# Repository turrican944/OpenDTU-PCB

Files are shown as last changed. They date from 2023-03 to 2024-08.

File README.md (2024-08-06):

# OpenDTU-PCB      
   
Eine Leiterplatte für OpenDTU oder Ahoy mit Oled Display.
Gehäuse Gainta G203CMF 115 x 65 x 40

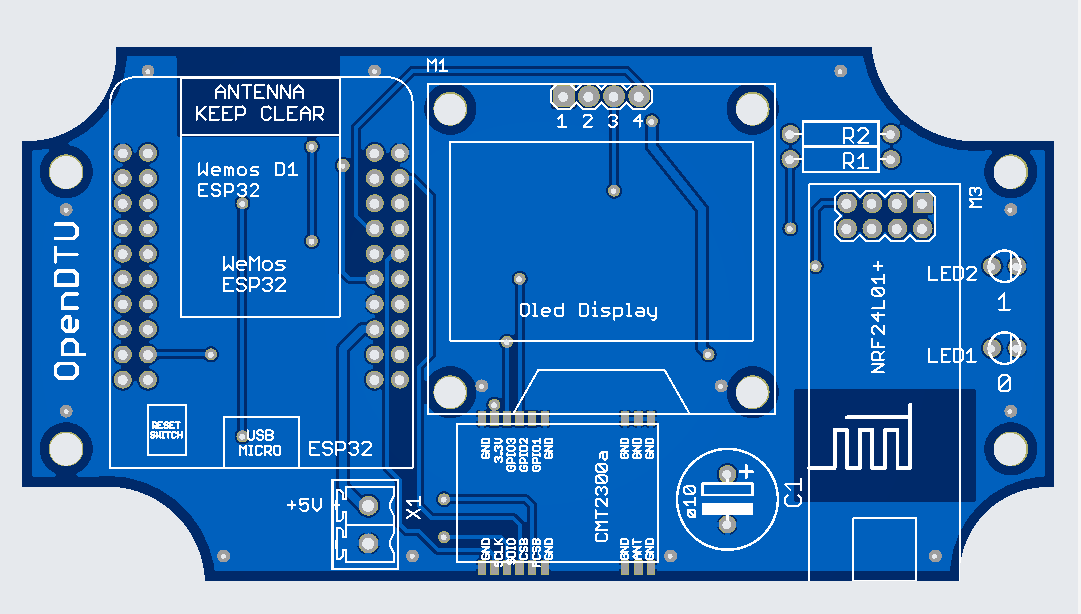
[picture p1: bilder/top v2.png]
Top

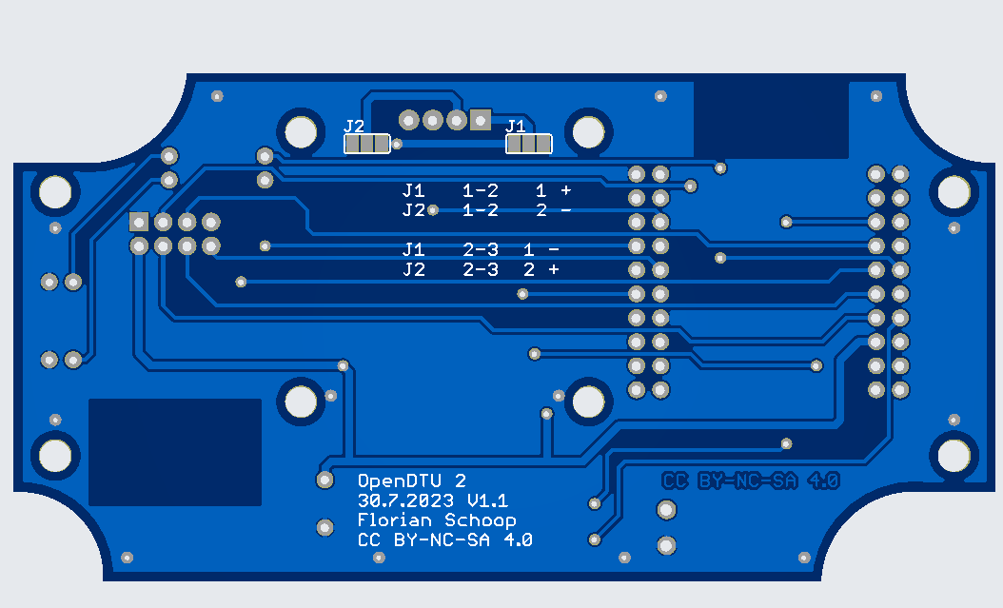
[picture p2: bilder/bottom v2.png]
Bottom

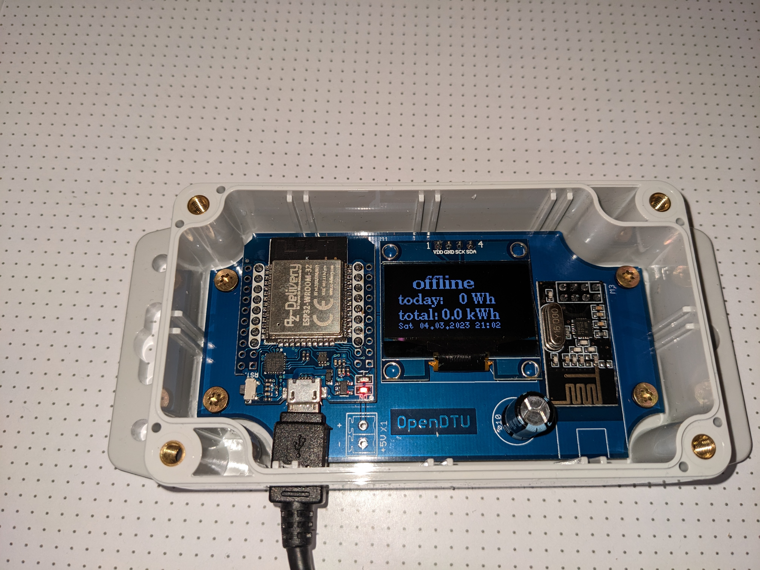
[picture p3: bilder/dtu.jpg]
dtu


Neue PCB Version jetzt mit CMT2300a und NRF24L01+
Es kann ein 1.3" Oled oder 0.9" I2C Oled verbaut werden. Die Polung der Spannungsversorgung ist über Jumper einstellbar. NRF24L01+ als Standart mit PCB Antenne oder auch als Version mit externer Antenne.
Es kann ein Wemos D1 mini oder ein Wemos D1 ESP32 verbaut werden. Für OpenDTU wird der Wemos D1 ESP32 benötigt.

Das GPIO Pinning ist das Standartpinning vom AhoyDTU. OpenDTU muss entsprechend auf angepasst werden (Deviceprofil.json für OpenDTU mit und ohne Display).
GPIO Pins OpenDTU: <br>
NRF: <br>
IO17 IRQ <br>
IO16 CE <br>
IO05 CS <br>
IO23 MOSI <br>
IO19 MISO <br>
IO18 SCK <br>
Display: <br>
IO22 SCL <br>
IO21 SDA <br>
CMT2300a: <br>
IO14 SDIO <br>
IO12 SCLK <br>
IO27 CSN <br>
IO26 FCSB <br>
IO04 GPIO2 <br>
IO13 GPIO3 <br>
LED: <br>
IO32 LED0 <br>
IO33 LED1 <br>

Die Pins legt man am besten schon in der Platformio.ini fest. Der ESP D1 Mini ist in der Platformio.ini schon enthalten allerdings sind dort IO16 und IO17 vertauscht. Flasht man nun den ESP32 wenn der schon auf de Platine ist, gibts beim Starten immer einen Interrupt vom Funkmodul (Pinning stimmt ja nicht) und ggf. kommt man dann nicht auf das WebIF. Also am besten die Pins des Funkmodul schon vorher ändern oder ESP32 erst flashen, devices config nachladen und ESP32 auf der Platine verbauen.

Bauteile: <br>
Wemos D1 ESP32 (für OpenDTU oder Ahoy) https://www.az-delivery.de/collections/esp32/products/esp32-d1-mini <br>
NRF24L01+ Funkmodul <br>
470uF Kondensator (es müssen wohl nicht umbedingt 470uF sein, weniger geht wohl auch ggf das nehmen was in der Bastelkiste grade ist)<br>
Minicombicon wenn die Stromversorgung nicht über den USB Port erfolgen soll. https://www.reichelt.de/stiftleiste-2-pol-rm-3-81-mm-0--ctb932ve-2-p292580.html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 <br>
Gainta G203CMF 115 x 65 x 40 Gehäuse https://www.conrad.de/de/p/gainta-g203cmf-universal-gehaeuse-115-x-65-x-40-polycarbonat-hellgrau-klar-1-st-2356897.html <br>
Ahoy mit einem ESP32 habe ich auf der aktuelle Platine nicht getestet.

Olimex ESP32 Poe
Adapterplatine CMT2300a auf Olimex poe Board
Olimex1
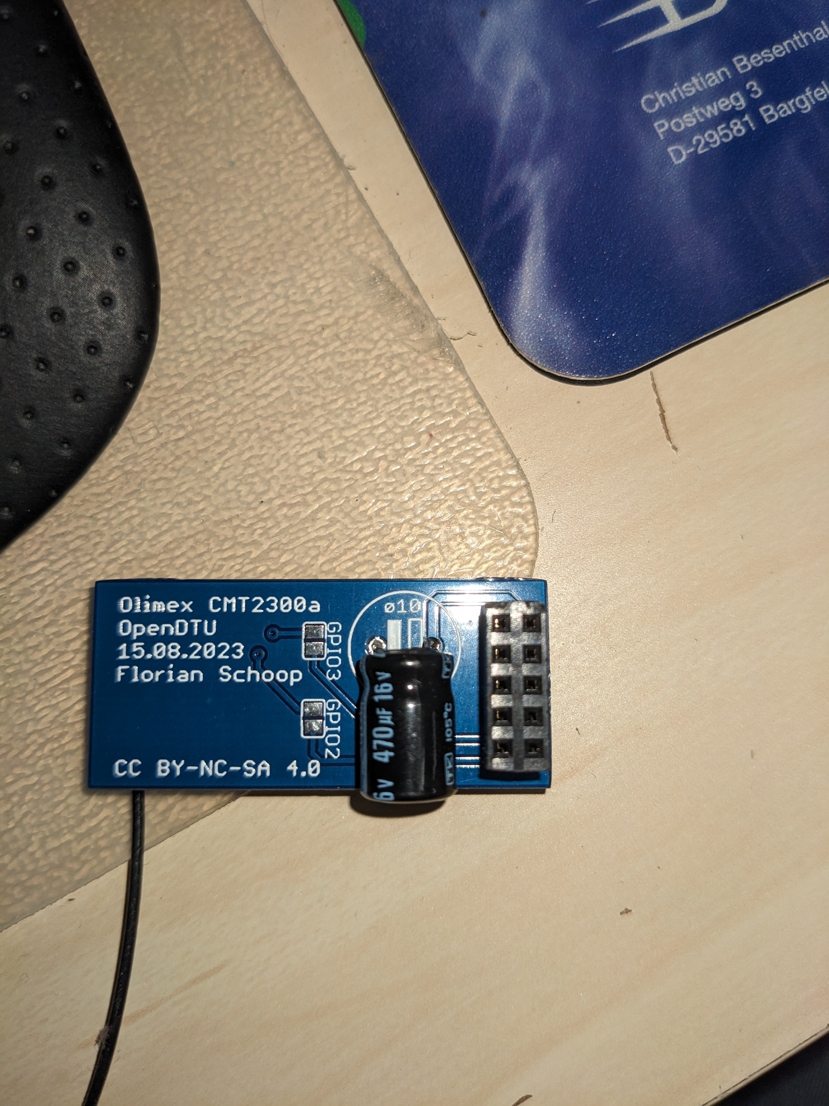
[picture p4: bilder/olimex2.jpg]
Olimex1

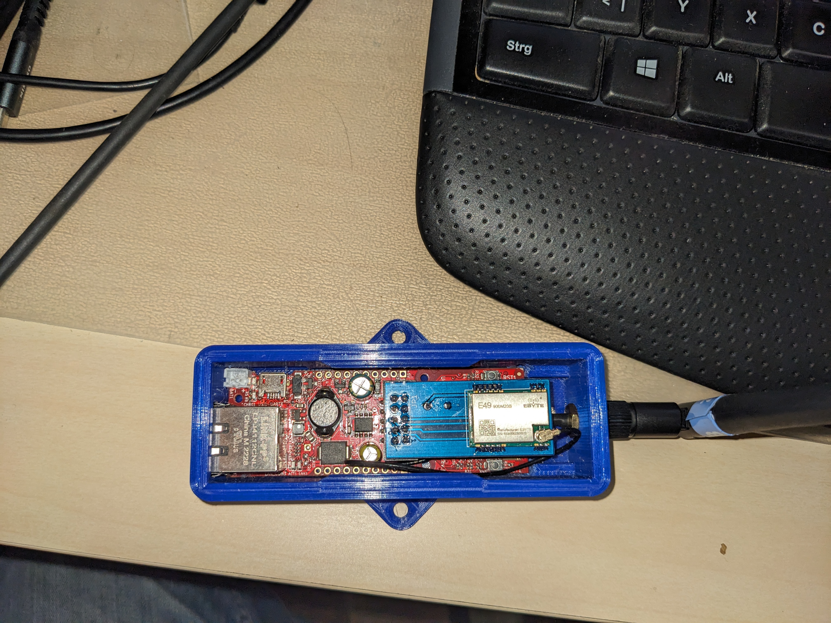
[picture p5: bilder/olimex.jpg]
Olimex1

Die Gerberdaten der Olimex Platine sind auch Panel 2x4 vorhanden.

Gehäuse für den Olimex ISO
https://www.thingiverse.com/thing:6489072 <br>
Gehäuse Olimex https://www.thingiverse.com/thing:4860626 (das ist das auf dem Bild)



Dieses Werk ist lizenziert unter einer [Creative Commons Namensnennung - Nicht-kommerziell - Weitergabe unter gleichen Bedingungen 4.0 International Lizenz](http://creativecommons.org/licenses/by-nc-sa/4.0/).

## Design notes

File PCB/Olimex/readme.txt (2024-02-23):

olimex_muster.zip enthält alle Gerber und Excellon Daten zum Fertigen z.b. bei JLCPCB 8 Muster sind auf einer Leiterplatte.
Wenn man die Standartmenge mit 5 Leiterplatten bestellt bekommt man also 40 Leiterplatten 

olimex.zip enthält die Gerber, Excellon und Eagle Daten für eine Leiterplatte.

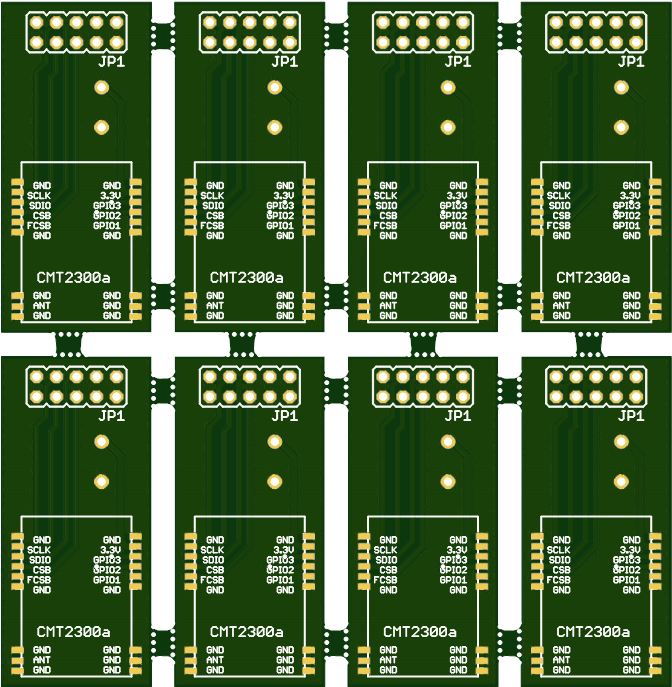
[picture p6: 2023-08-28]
PCB/Olimex/Untitled_Combined_Top.png

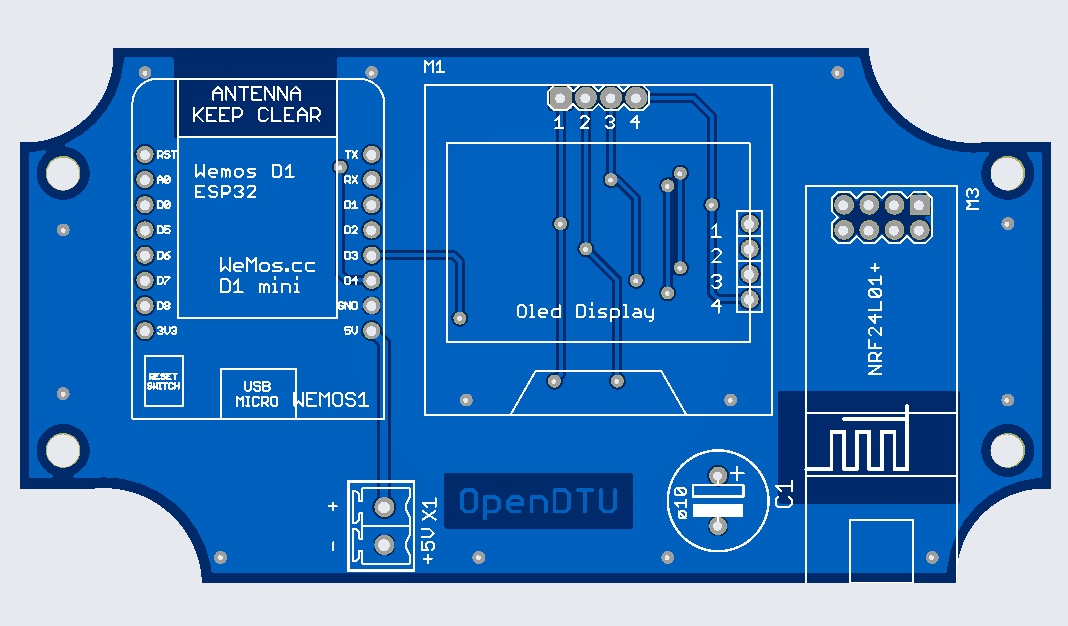
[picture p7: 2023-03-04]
bilder/Top.png

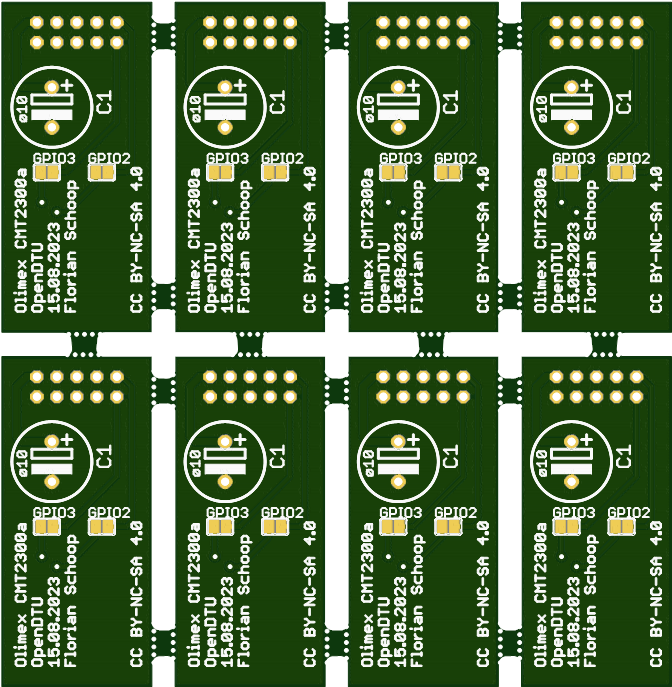
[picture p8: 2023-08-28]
PCB/Olimex/Untitled_Combined_Bottom.png

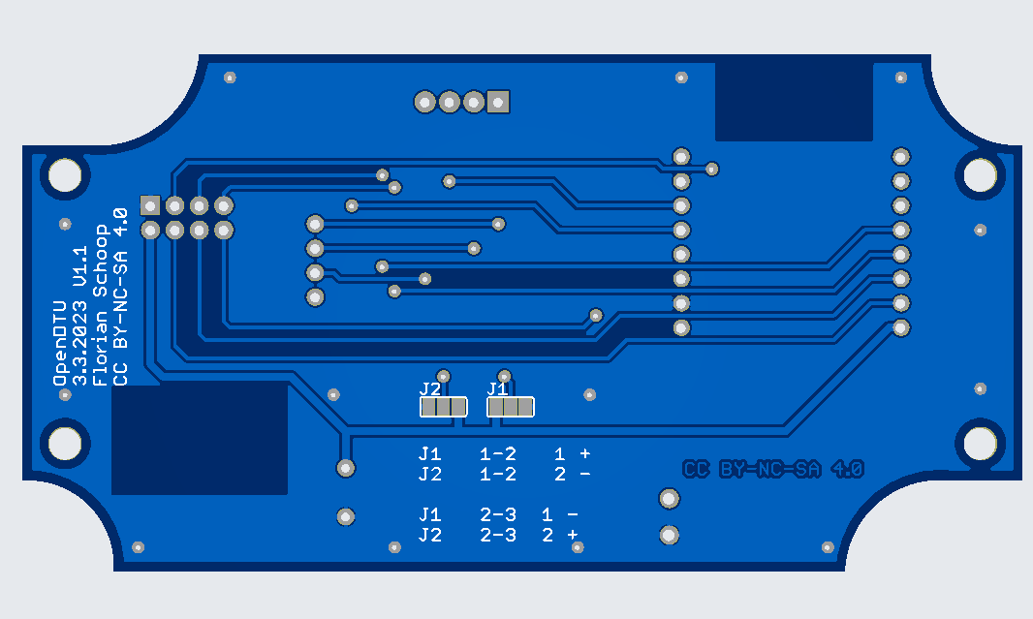
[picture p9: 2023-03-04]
bilder/bottom.png

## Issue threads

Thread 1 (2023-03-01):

Test PCBs // Add Contact Data

basst22778, 2023-03-01:
Hi,
Ich hätte Interesse an PCBs aus Deiner Testbestellung. Wenn du noch welche übrig hasts…

Es gibt aber keine Kontaktdaten in deinem Repo.

—
BassT

turrican944, 2023-03-01:
Moin
Ne sind noch keine Kontaktdaten drin, ich habe es auch noch nicht fertig.
Leiterplatten sind noch nicht da, aber ich habe davon dann auch leider
keine mehr über.

Gruß Florian

basst22778 ***@***.***> schrieb am Mi., 1. März 2023, 21:12:

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

basst22778, 2023-03-01:
Alles klar! dann warte ich mal ab ob das Layout bei Dir funktioniert und geb dann selbst ne Bestellung auf.

turrican944, 2023-03-02:
Moin
Ich gehe schon davon aus daß es funktioniert. Ich habe noch bischen was
geändert. Ein Text war noch versetzt und noch ein paar Masse
Durchkontaktierungen mehr rein, ich warte aber immer noch auf die erste
Charge. Die Änderungen sollte aber wenn die erste funktioniert auch passen.
Aber evtl Order ich nochmal nach weil natürlich alle Kumpels sowas wollen.
Aber es ist ja immer so Zeit ist knapp.

Gruß Florian

basst22778 ***@***.***> schrieb am Mi., 1. März 2023, 23:34:

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

Closed 2023-03-01.

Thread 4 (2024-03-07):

Kleiner Fehler im opendtu V2.pdf

swan99de, 2024-03-07:
In die Beschriftung für die Polung der Jumper hat sich im opendtu V2.pdf ein kleiner Fehler eingeschlichen.
J1 1-2 1+   J2 2-3 1-
J2 1-2 2-   J2 2-3 2+
Jumper2 ist 3x und Jumper1 nur 1x aufgeführt

Der Aufdruck auf der Platine ist korrekt
J1 1-2 1+
J2 1-2 2-

J1 2-3 1-
J2 2-3 2+

turrican944, 2024-03-08:
Moin
Guck an ist mir noch garnicht aufgefallen ;-) , ich habe es mal korrigiert, tippfehler kommen halt mal vor.

Closed 2024-03-08.

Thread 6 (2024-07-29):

WT32-ETH01 Variante?

KlausHans, 2024-07-29:
Hallo, coole Platine, die meiner all-in-one-Vorstellung sehr nahe kommt. Ich bin aber kein Fan von Wlan. Wäre es möglich, dass du eine Variante für das wt32-eth01-Board machst?
Ich bin leider mit PCB-Design komplett unbewandert und evtl ist es für dich ein Klacks.
Folgende Dinge schweben mir vor:
- Größe und Außenkontur ist egal, ich würde eh ein Gehäuse designen und 3D-drucken
- der Ethernetconnector würde wohl eine Art cutout benötigen, da er höher als die Pinsockel ist
- das WT32-ETH01 sollte so positioniert sein, dass der Ethernetconnector über den Rand hinaus ragt, damit er in einer Gehäusewand übergehen kann
- Display muss nicht direkt auf der Platine Platz finden, die Anschlüsse reichen

Vielleicht hast du eh schon mal drüber nachgedacht. Das Olimex-Board ist mMn unnötig teuer und Poe hat kaum jemand (ich persönlich kenne niemanden in meinem Bekanntenkreis).

turrican944, 2024-08-06:
Moin
Den kenn ich gar nicht.
Ich bin auch keine wirklicher Fan von WLAN , aber ich habe Power over Ethernet und deshalb mal den Adapter zum aufstecken auf den Olimex gemacht. Der kann aber nur HMS WR (ich habe zurzeit auch keine anderen). Ich wollte für den Olimex mal eine Platine machen wo Display und das NRF mit drauf ist (CMT kann ja weiter huckepack bleiben oder auch mit drauf) aber da ich weder das Display wirklich brauche noch die 2,4Ghz habe ich da bislang nix gemacht.
Ist ja nun nicht so dass es mal ebend schnell geht. Leiterplatten erstellen , dann muss ich das aufbauen und testen ob das alles geht. Momentan habe ich da wenig Zeit zu und die Geschichte Ethernet aber mit Netzteil ist irgendwie nix was ich brauchen könnte.
Wenn ich im Herbst/Winter vielleicht mal etwas Zeit finde und eine Platine mit Display usw für den Olimex machen sollte kann ich ja Mal schauen ob der andere mit Ethernet da auch rauf passt.

KlausHans, 2024-08-06:
Alles klar, vielen Dank für die Antwort. Verständlich.
Einer All-in-one-Platine für das Olimexboard wäre ich auch nicht abgeneigt. So viele Dtus braucht man ja nicht, da wären die Mehrkosten dafür auch ok.

turrican944, 2024-08-06:
Moin
für den Olimex habe ich das mal vor zu machen, weis aber noch nicht wann
ich dazu komme.  Denke das wird irgendwie herbst/winter werden.
Im Bild mal der Testaufbau Olimex mit NRF, CMT und Display.
Gruß Flo

Am Di., 6. Aug. 2024 um 14:05 Uhr schrieb KlausHans <
***@***.***>:

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

KlausHans, 2024-09-23:
Ich freue mich auf die Variante und bin gespannt.

Ich sehe kein Bild. 🤔

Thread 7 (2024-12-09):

Gehäuse aus dem 3d-Drucker

KlausHans, 2024-12-09:
Moin, ich wollte nur kurz mein Gehäuse zeigen, vllt ist es für den einen oder anderen interessant und evtl sogar eine Erwähnung in der Readme wert: https://www.printables.com/model/1102696-case-for-opendtu-pcb-by-turrican944

Ansonsten kann das issue direkt geschlossen werden. :)

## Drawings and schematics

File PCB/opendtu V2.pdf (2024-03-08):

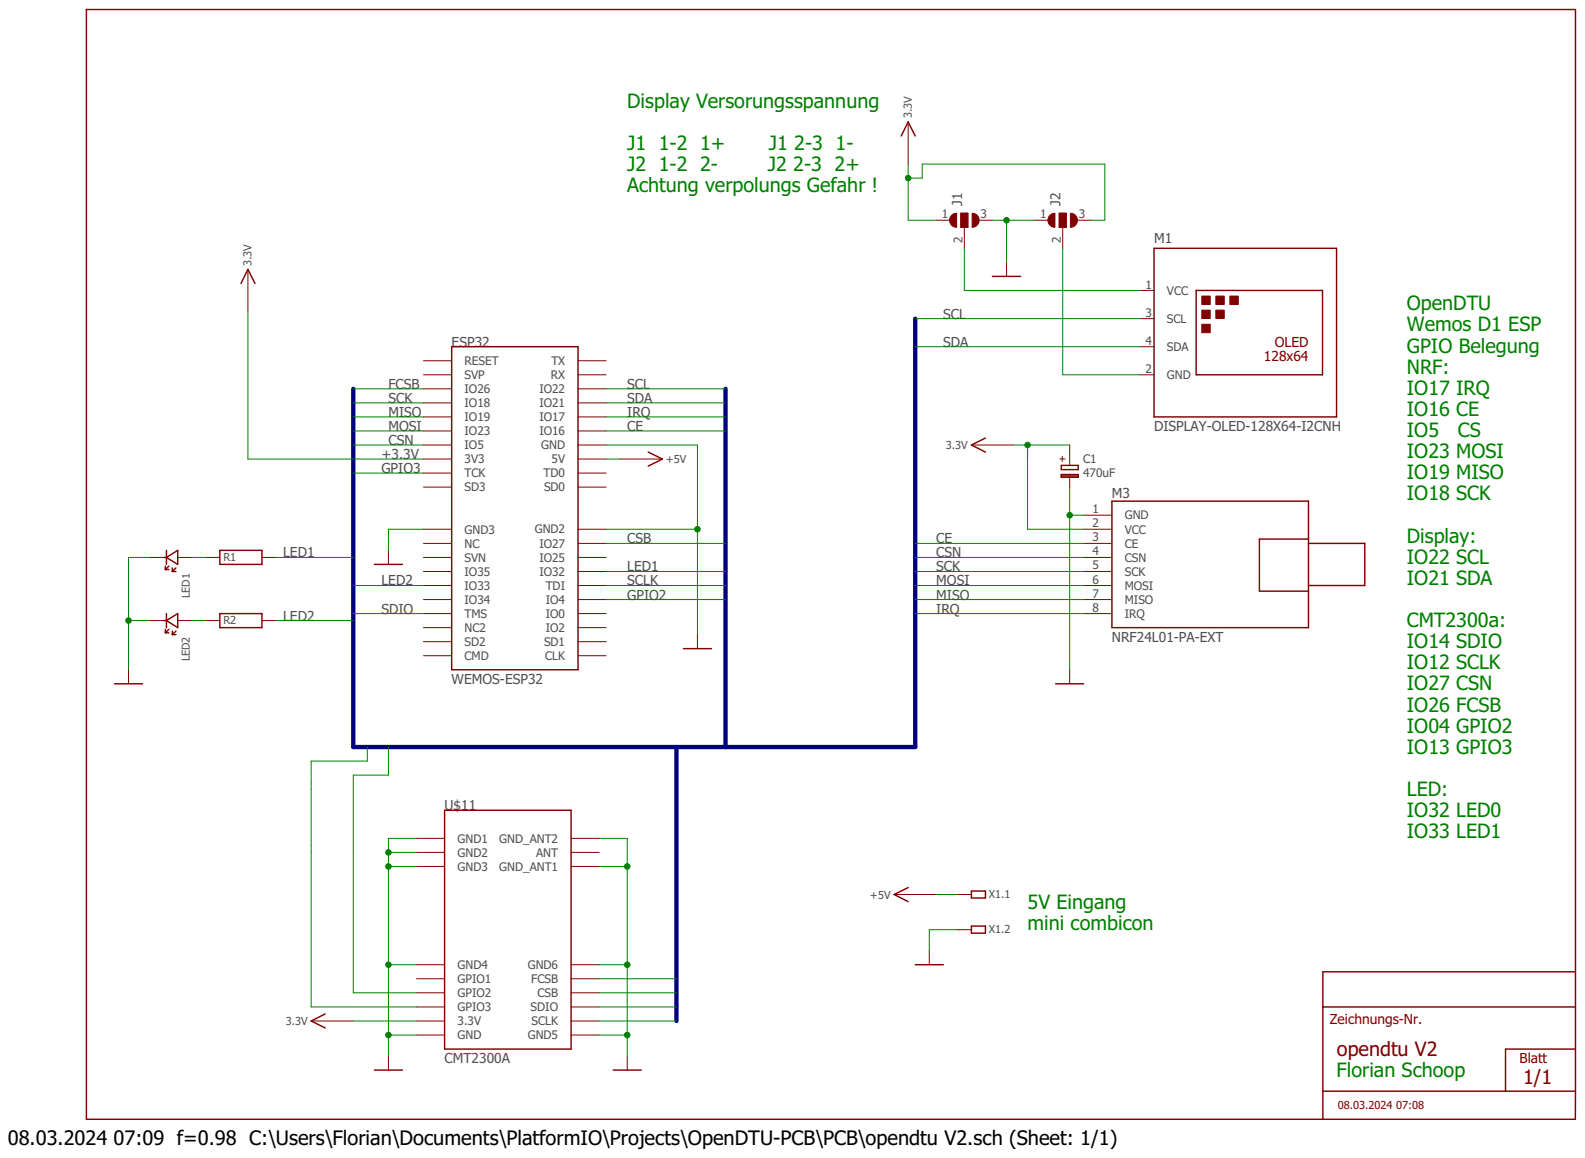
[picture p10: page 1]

SCK | SDA
MISO | IRQ

08.03.2024 07:09 f=0.98 C:\Users\Florian\Documents\PlatformIO\Projects\OpenDTU-PCB\PCB\opendtu V2.sch (Sheet: 1/1)

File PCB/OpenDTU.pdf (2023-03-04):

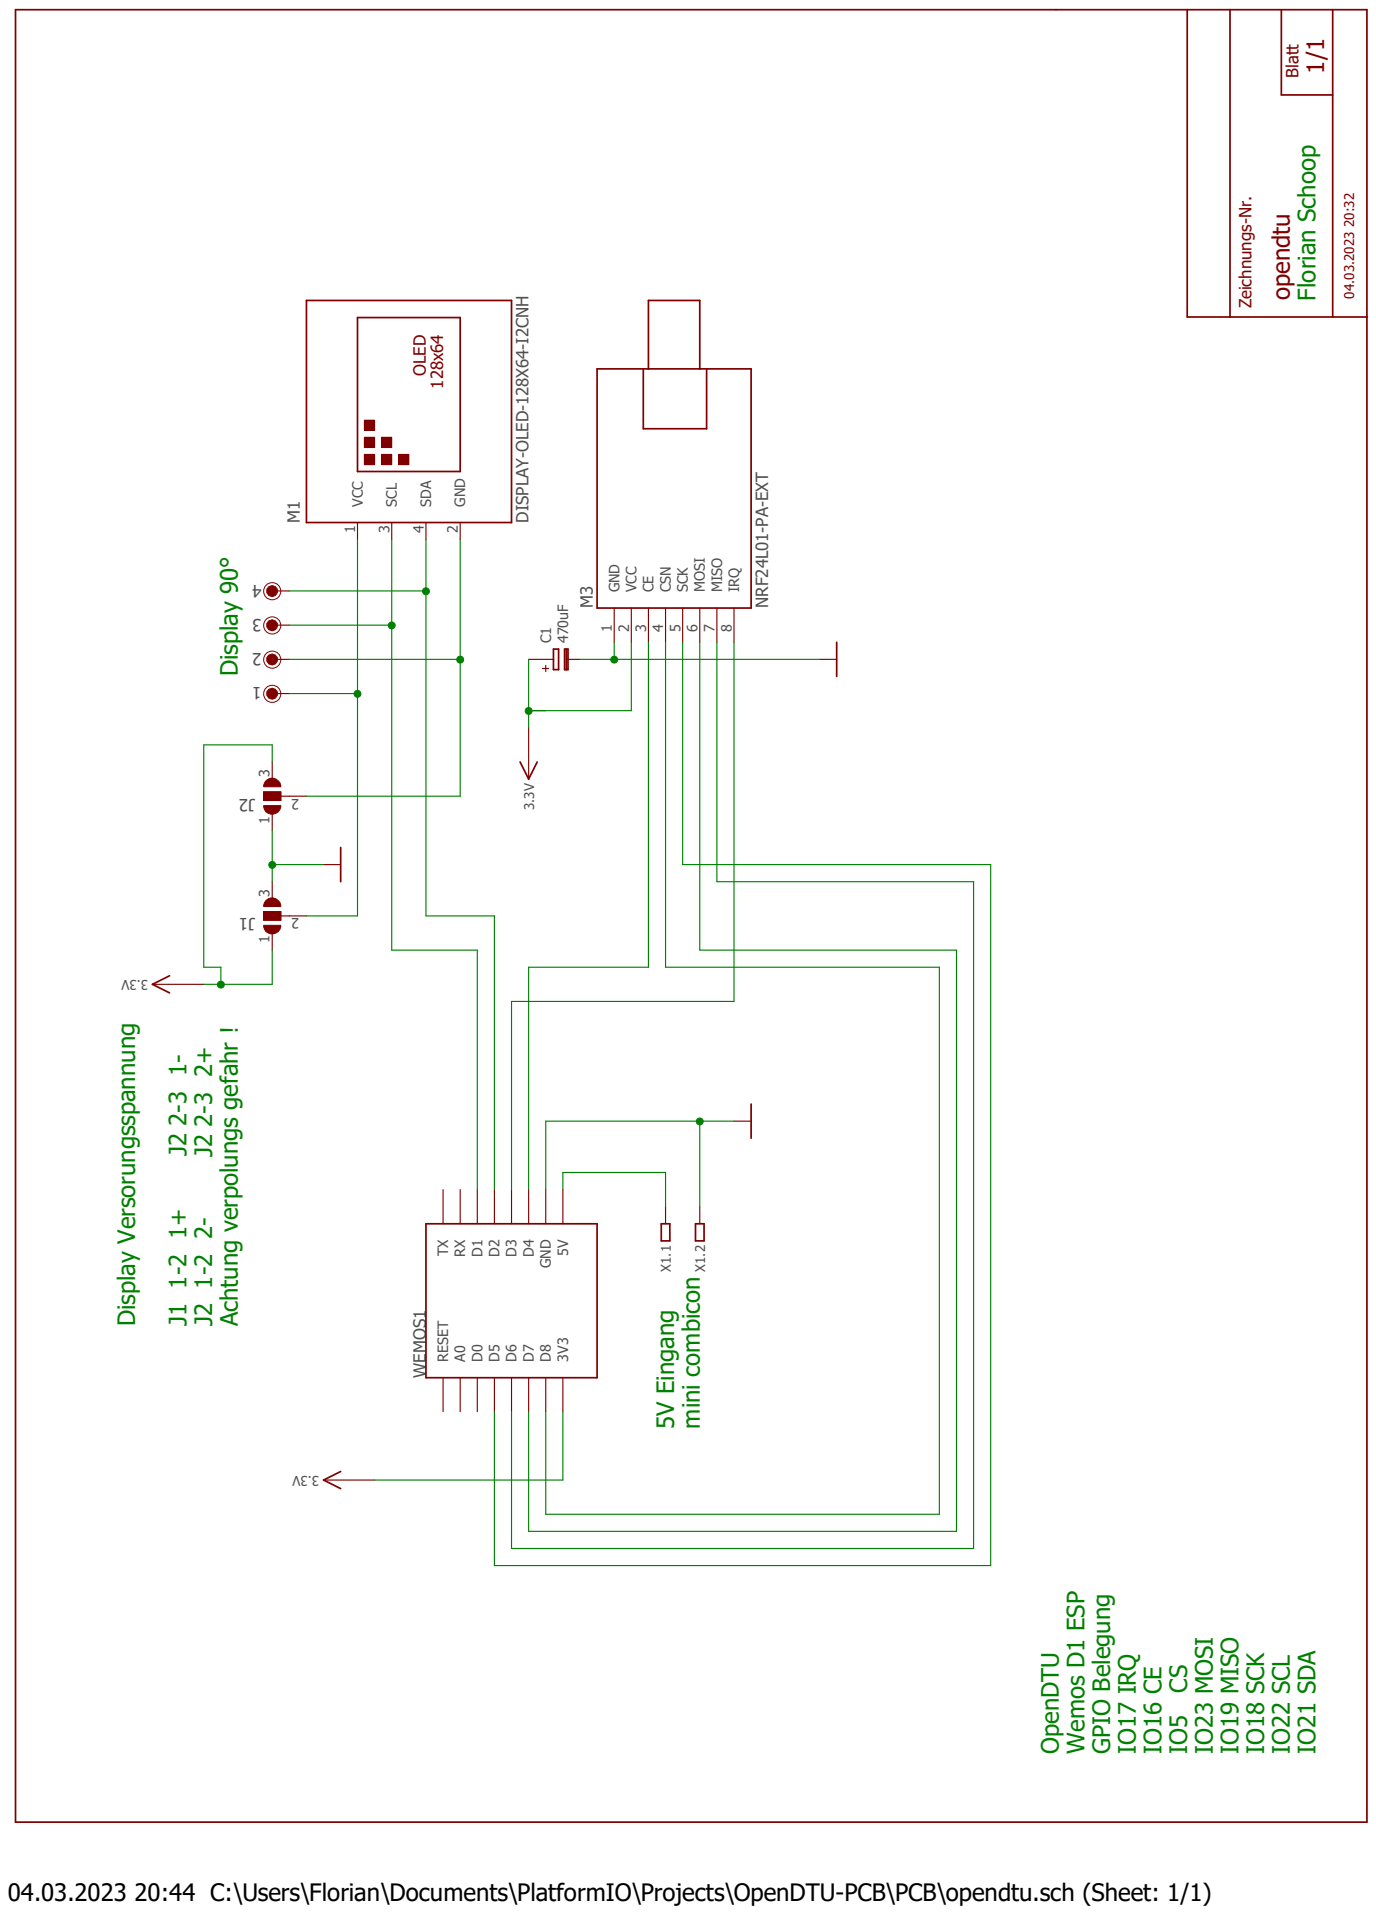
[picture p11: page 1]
1 VCC 2 CE; 3 CSN 4 SCK; 5 MOSI 6 MISO 7 IRQ; 8 M3 GND 2 VCC; 1 SCL 3 SDA

04.03.2023 20:44 C:\Users\Florian\Documents\PlatformIO\Projects\OpenDTU-PCB\PCB\opendtu.sch (Sheet: 1/1) NRF24L01⁻PA⁻EXT DISPLAY⁻OLED⁻¹²⁸X64⁻I2CNH

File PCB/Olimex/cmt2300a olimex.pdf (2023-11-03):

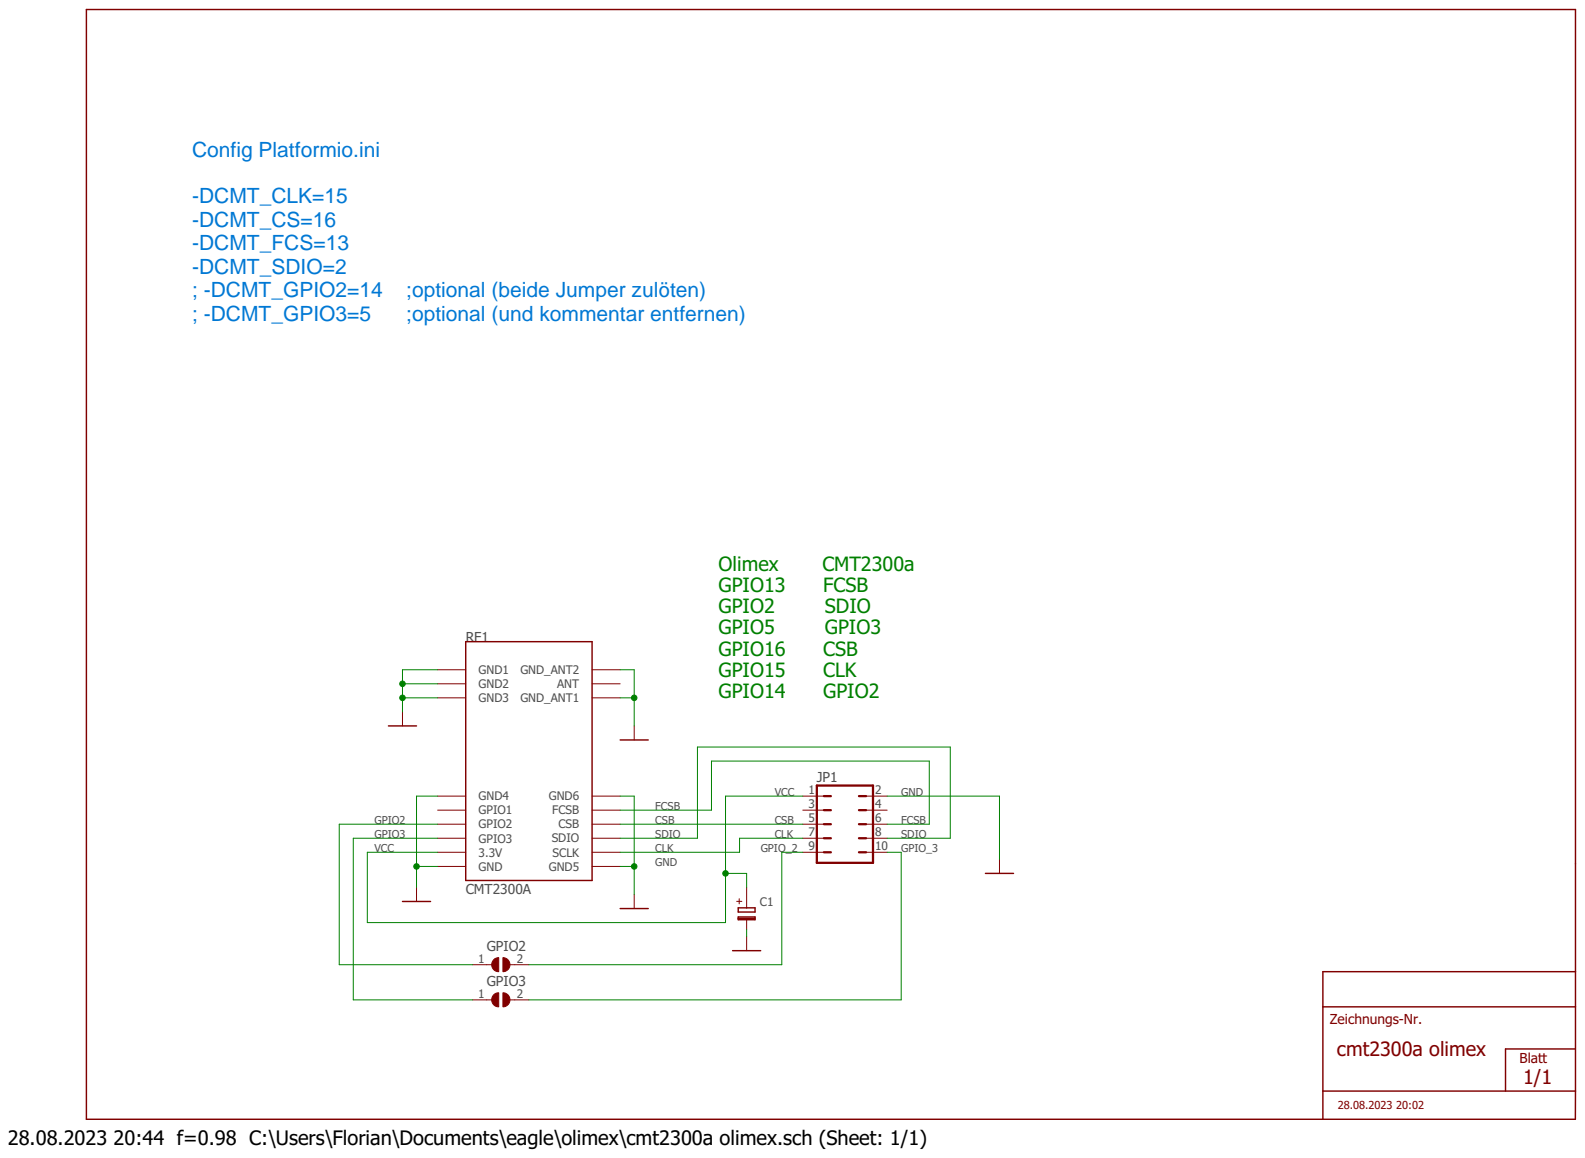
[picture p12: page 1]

3 5 | 4 6 SDIO
SDIO | FCSB GPIO3

28.08.2023 20:44 f=0.98 C:\Users\Florian\Documents\eagle\olimex\cmt2300a olimex.sch (Sheet: 1/1)

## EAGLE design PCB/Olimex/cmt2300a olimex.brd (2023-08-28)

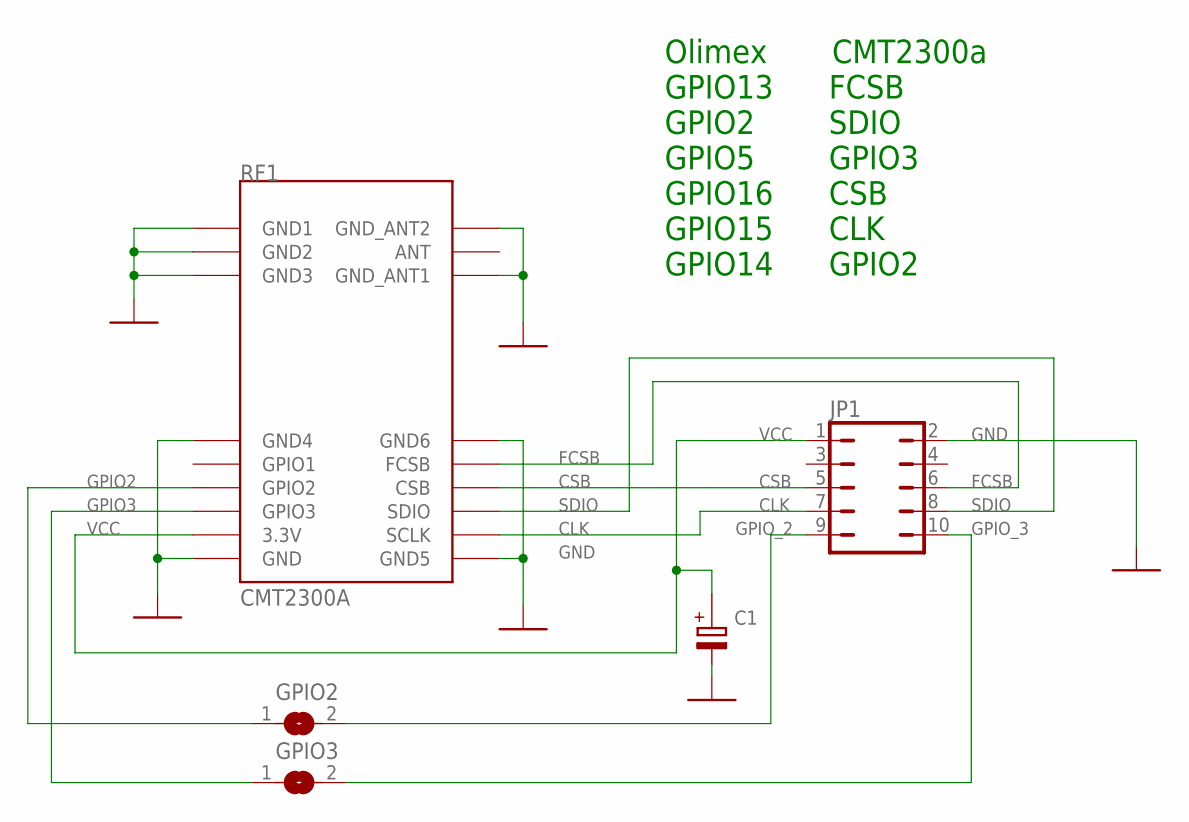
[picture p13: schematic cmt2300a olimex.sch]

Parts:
C1: S470µ/16; EB10D
GPIO2, GPIO3: SJ
JP1: JP5Q_OT
RF1: CMT2300A

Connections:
CLK: JP1.7, RF1.SCLK
CSB: JP1.5, RF1.CSB
FCSB: JP1.6, RF1.FCSB
GND: C1.-, JP1.2, RF1.GND, RF1.GND1, RF1.GND2, RF1.GND3, RF1.GND4, RF1.GND5, RF1.GND6, RF1.GND_ANT1, RF1.GND_ANT2
GPIO2: GPIO2.1, RF1.GPIO2
GPIO3: GPIO3.1, RF1.GPIO3
GPIO_2: GPIO2.2, JP1.9
GPIO_3: GPIO3.2, JP1.10
SDIO: JP1.8, RF1.SDIO
VCC: C1.+, JP1.1, RF1.3.3V

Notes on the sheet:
Olimex CMT2300a GPIO13 FCSB GPIO2 SDIO GPIO5 GPIO3 GPIO16 CSB GPIO15 CLK GPIO14 GPIO2

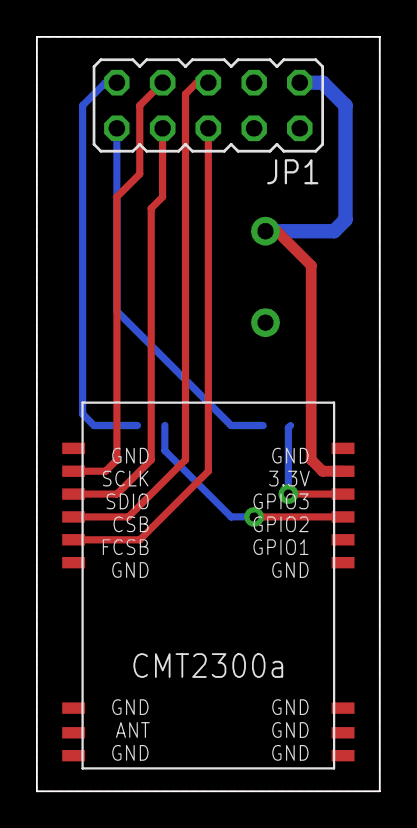
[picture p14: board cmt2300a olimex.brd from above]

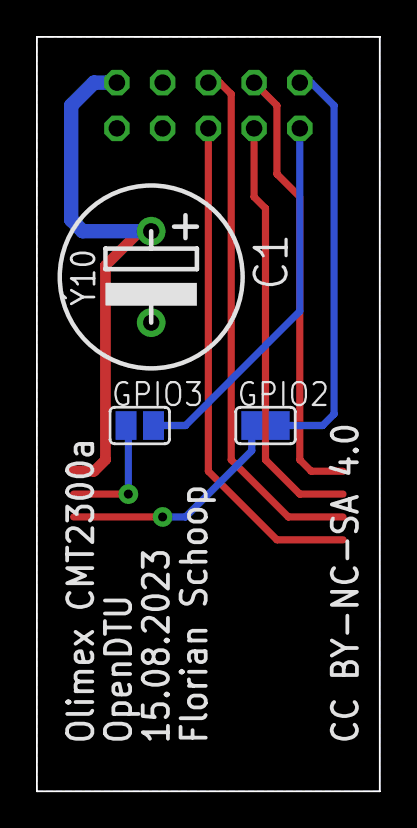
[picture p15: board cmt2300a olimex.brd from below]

Board: 2 copper layers, 19.1 x 41.9 mm, 5 parts (3 on the bottom side), 10 nets.

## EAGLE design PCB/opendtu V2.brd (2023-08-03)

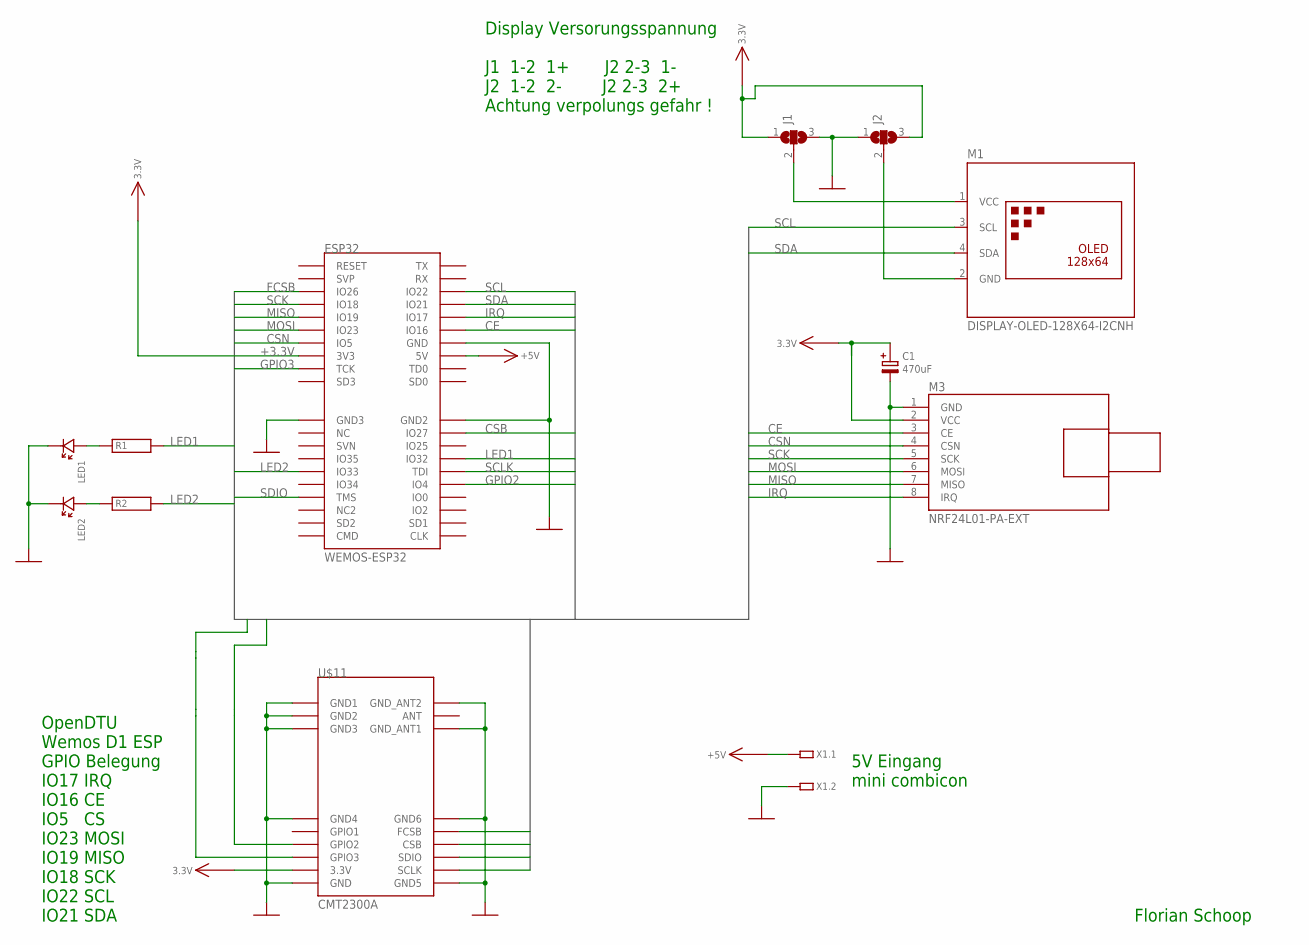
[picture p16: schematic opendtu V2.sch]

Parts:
C1: 470uF; EB10D
ESP32: WEMOS-ESP32
J1, J2: SJ2W; SJ_2
LED1, LED2: LED3MM
M1: DISPLAY-OLED-128X64-I2CNH; DISPLAY-OLED-128X64-I2C_NH
M3: NRF24L01-PA-EXT
R1, R2: WIDERSAND; 1/8W
U$11: CMT2300A
X1: MCV1,5/2G; MCV1,5/2

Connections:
+3.3V: C1.+, ESP32.3V3, J1.1, J2.3, M3.2 (VCC), U$11.3.3V
+5V: ESP32.VCC (5V), X1.1
CE: ESP32.IO16, M3.3 (CE)
CSB: ESP32.IO27, U$11.CSB
CSN: ESP32.IO5, M3.4 (CSN)
FCSB: ESP32.IO26, U$11.FCSB
GND: C1.-, ESP32.GND, ESP32.GND2, ESP32.GND3, J1.3, J2.1, LED1.K (KAT), LED2.K (KAT), M3.1 (GND), U$11.GND, U$11.GND1, U$11.GND2, U$11.GND3, U$11.GND4, U$11.GND5, U$11.GND6, U$11.GND_ANT1, U$11.GND_ANT2, X1.2
GPIO2: ESP32.IO4, U$11.GPIO2
GPIO3: ESP32.TCK, U$11.GPIO3
IRQ: ESP32.IO17, M3.8 (IRQ)
LED1: ESP32.IO32, R1.2
LED2: ESP32.IO33, R2.2
MISO: ESP32.IO19, M3.7 (MISO)
MOSI: ESP32.IO23, M3.6 (MOSI)
unnamed: J2.2, M1.2 (GND)
unnamed: J1.2, M1.1 (VCC)
unnamed: LED2.A (ANO), R2.1
unnamed: LED1.A (ANO), R1.1
SCK: ESP32.IO18, M3.5 (SCK)
SCL: ESP32.IO22, M1.3 (SCL)
SCLK: ESP32.TDI, U$11.SCLK
SDA: ESP32.IO21, M1.4 (SDA)
SDIO: ESP32.TMS, U$11.SDIO

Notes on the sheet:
Display Versorungsspannung J1 1-2 1+ J2 2-3 1- J2 1-2 2- J2 2-3 2+ Achtung verpolungs gefahr !
OpenDTU Wemos D1 ESP GPIO Belegung IO17 IRQ IO16 CE IO5 CS IO23 MOSI IO19 MISO IO18 SCK IO22 SCL IO21 SDA
Florian Schoop
5V Eingang mini combicon

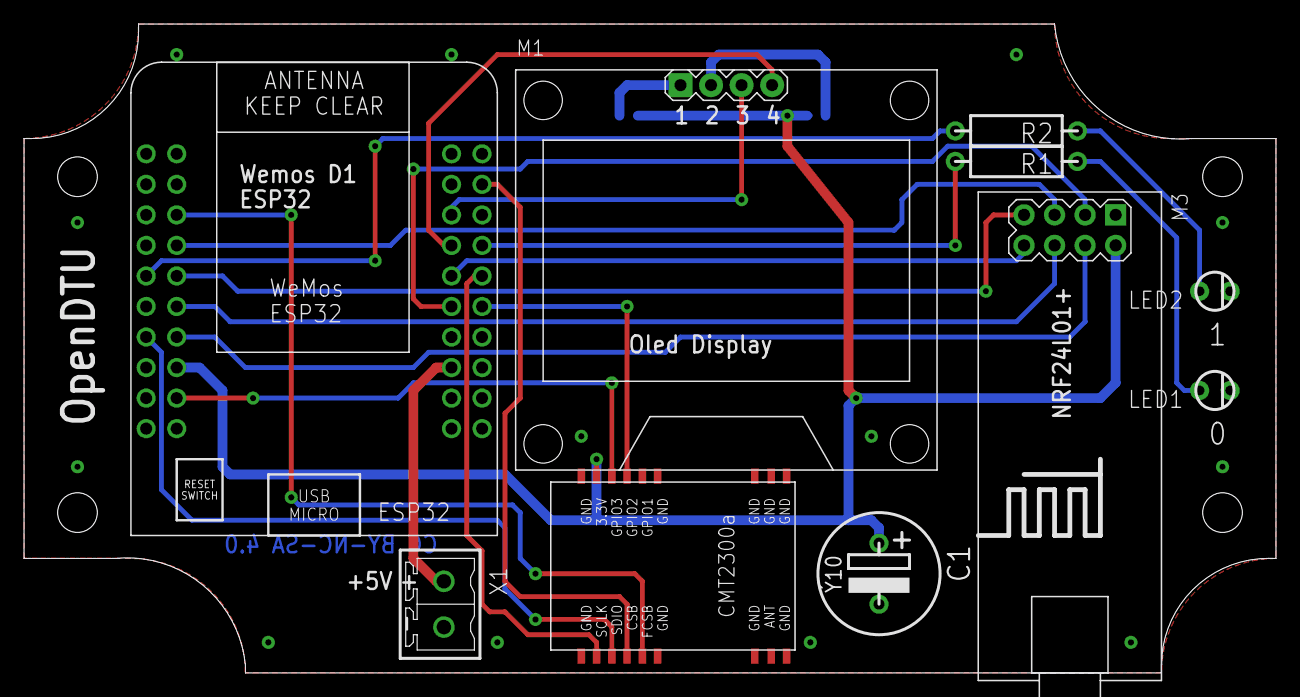
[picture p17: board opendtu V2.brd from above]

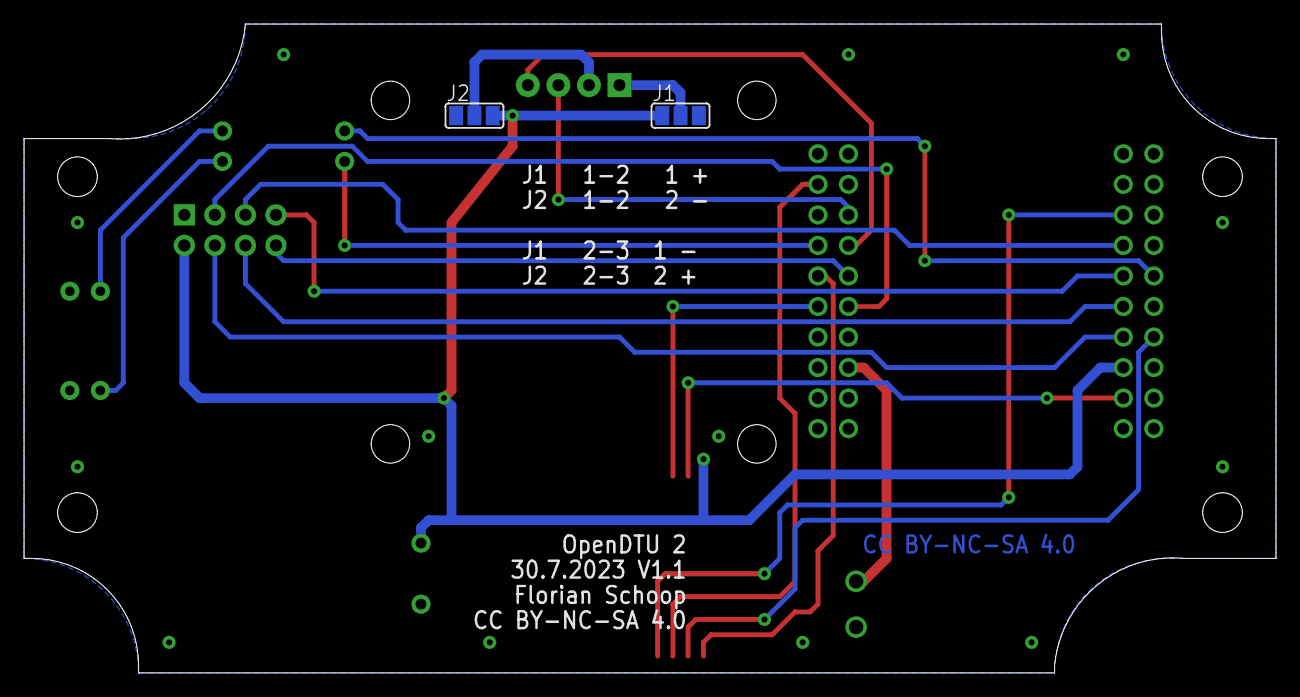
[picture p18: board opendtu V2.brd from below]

Board: 2 copper layers, 104.1 x 54.0 mm, 12 parts (2 on the bottom side), 23 nets.

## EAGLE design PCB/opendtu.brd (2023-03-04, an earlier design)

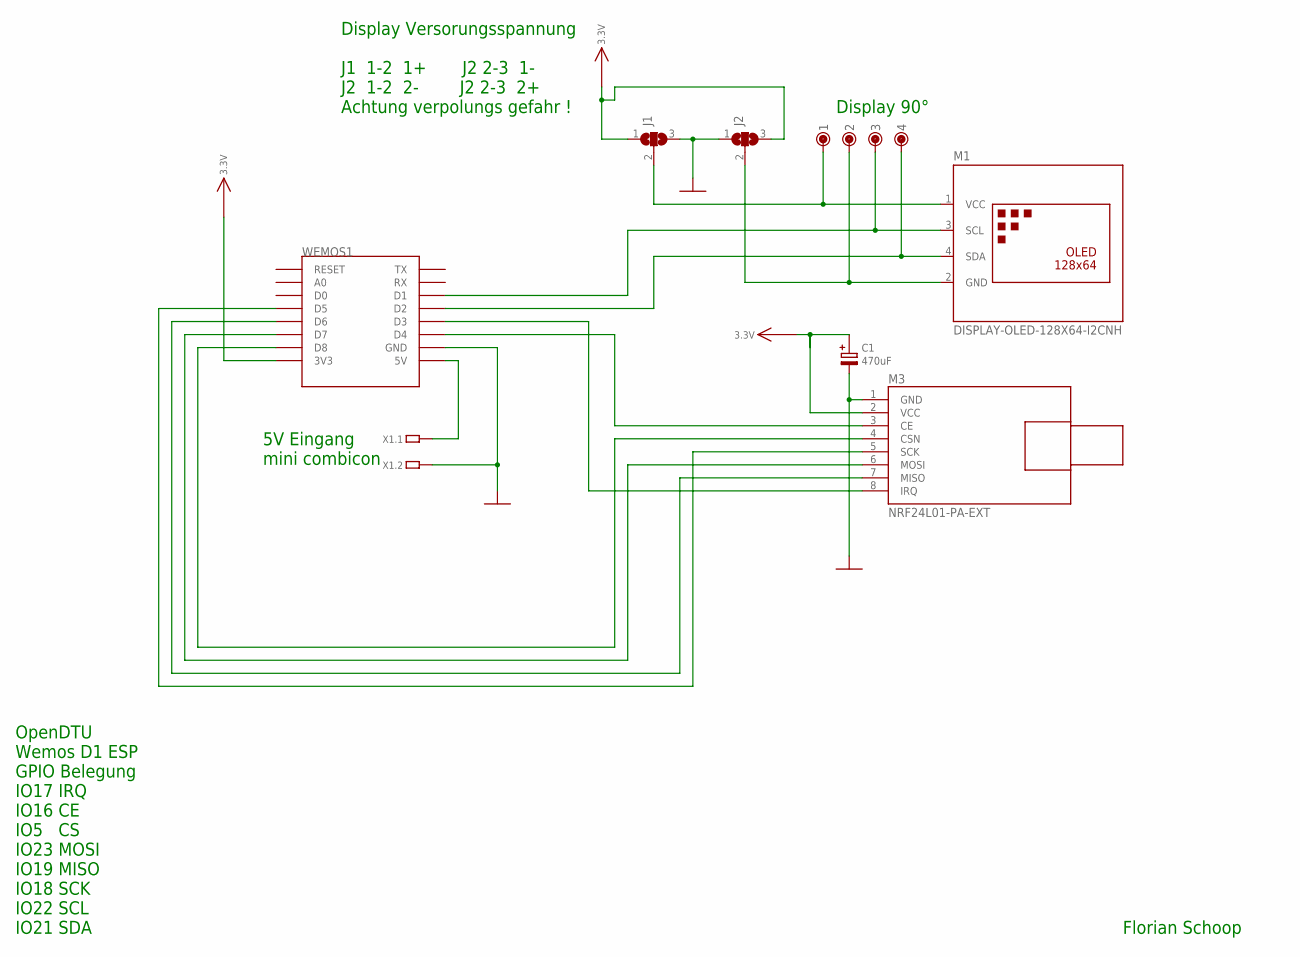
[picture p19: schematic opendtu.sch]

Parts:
1, 2, 3, 4: PINGERAD
C1: 470uF; EB10D
J1, J2: SJ2W; SJ_2
M1: DISPLAY-OLED-128X64-I2CNH; DISPLAY-OLED-128X64-I2C_NH
M3: NRF24L01-PA-EXT
WEMOS1: WEMOS-D1-MINI
X1: MCV1,5/2G; MCV1,5/2

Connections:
+3.3V: C1.+, J1.1, J2.3, M3.2 (VCC), WEMOS1.3V3
GND: C1.-, J1.3, J2.1, M3.1 (GND), WEMOS1.GND, X1.2
unnamed: 4.1, M1.4 (SDA), WEMOS1.D2
unnamed: 3.1, M1.3 (SCL), WEMOS1.D1
unnamed: 2.1, J2.2, M1.2 (GND)
unnamed: 1.1, J1.2, M1.1 (VCC)
unnamed: M3.3 (CE), WEMOS1.D4
unnamed: M3.4 (CSN), WEMOS1.D8
unnamed: M3.6 (MOSI), WEMOS1.D7
unnamed: M3.7 (MISO), WEMOS1.D6
unnamed: M3.5 (SCK), WEMOS1.D5
unnamed: M3.8 (IRQ), WEMOS1.D3
unnamed: WEMOS1.5V, X1.1

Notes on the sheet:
Display Versorungsspannung J1 1-2 1+ J2 2-3 1- J2 1-2 2- J2 2-3 2+ Achtung verpolungs gefahr !
Display 90°
OpenDTU Wemos D1 ESP GPIO Belegung IO17 IRQ IO16 CE IO5 CS IO23 MOSI IO19 MISO IO18 SCK IO22 SCL IO21 SDA
Florian Schoop
5V Eingang mini combicon

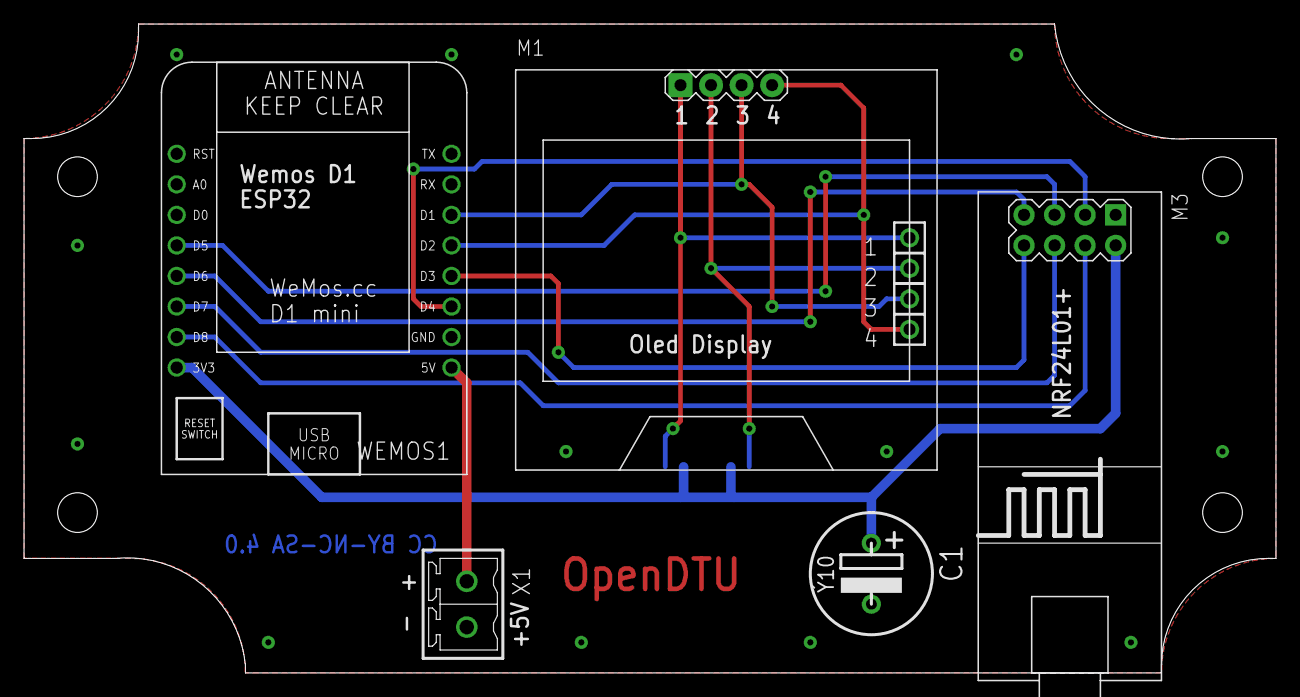
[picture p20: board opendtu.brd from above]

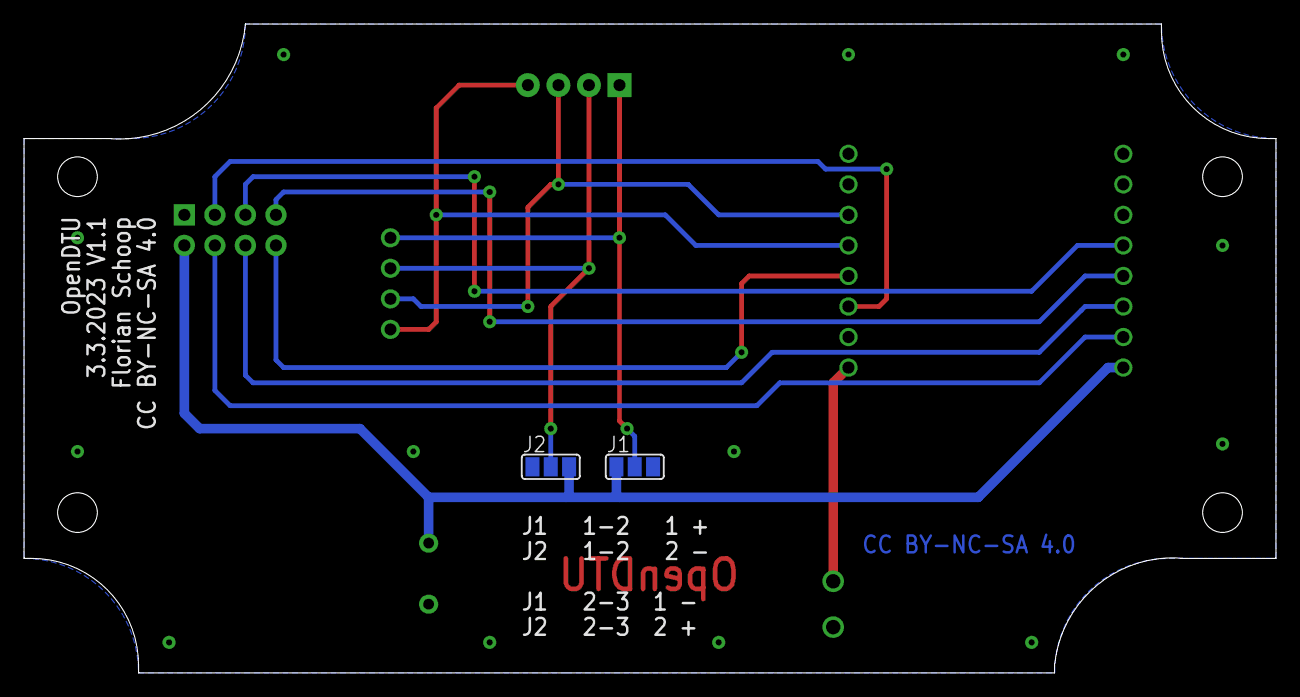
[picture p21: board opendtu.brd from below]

Board: 2 copper layers, 104.1 x 54.0 mm, 11 parts (2 on the bottom side), 13 nets.

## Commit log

2023-02-24 erste upload
    erster Upload
    [opendtu.GBL, opendtu.GBO, opendtu.GBS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]
2023-02-24 Create opendtu.sch
    Schaltplan
    [opendtu.sch]
2023-02-24 Schematic
    Schaltplan änderungen
    [opendtu.sch]
2023-02-24 Board
    Passlöcher vom Board entfernt. Werden zur Produktion nicht benötig. Passlöcher nur fürs Sieb & Meyer Fräsefile benötig. (für das Bohrmuster).
    [opendtu.brd]
2023-02-24 PCB Bilder
    Bilder
2023-02-28 Text Display
    Display Text geändert, damit der auch unter den PINs ist.
2023-03-02 masse
    Masse Via hinzugefügt
    [opendtu.brd]
2023-03-02 Create OpenDTU-V1.zip
    Zip Datei mit der ersten Version.
2023-03-03 Gerber V1.1
    V1.1 vom Gerber
    [opendtu.brd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]
2023-03-04 V1.1
    Text nochmal etwas verschoben. PDF vom Schaltplan hinzugefügt.
    [opendtu.brd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]
2023-03-05 add Deviceprofil.json
    Deviceprofil für ESP32, für OpenDTU. Nach dem Flashen vom OpenDTU kann diese Datei über das Webif geladen werden und damit die GPIO Pins passend auszuwählen. (kann natürlich auch schon beim Compilier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
2023-03-05 Create Device Profil D1 ESP32.json
2023-03-12 add platformio_override.ini
    Platformio_overide.ini passend für Wemos D1 ESP32 mit Display
2023-06-12 Update Device Profil D1 ESP32.json
    update Device profil
2023-07-30 add CMT2300a
    V2 mit CMT2300a (ungetestet !!)
    [opendtu V2.GBL, opendtu V2.GBO, opendtu V2.GBS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]
2023-07-30 plus war im weg
    plus war im weg
    [opendtu V2.brd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]
2023-08-03 Via geändert
    [opendtu V2.brd, opendtu V2.sch]
2023-08-15 Schaltplan PDF
    [opendtu V2.sch]
2023-08-28 add olimex
    [cmt2300a olimex.GBL, cmt2300a olimex.GBO, cmt2300a olimex.GBS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]
2023-08-28 Update README.md
    add olimex Board
2023-10-06 Update Device Profil D1 ESP32.json
    Add Olimex POE CMT2300a
2023-11-03 Update cmt2300a olimex.pdf
    pin config hinzugefügt
2023-11-03 Update Device Profil D1 ESP32.json
    Text änderungen
2024-01-07 Update Device Profil D1 ESP32.json
    Without these additional lines, which deactivate the pins for nrf24, Ethernet did not work. The problem seemed to come from the fact that pins are defined for the nrf24 in the standard configuration, which the Olimex board needs for Ethernet.
    After inserting these lines, Ethernet worked without any problems.
2024-02-23 Update README.md
    neue Leiterplatten Bilder mit CMT2300a und NRF
2024-02-23 move old files
    move old PCB to old folder, remove Eagle undo files
    [opendtu.GBL, opendtu.GBO, opendtu.GBS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]
2024-02-23 Update README.md
    add link Olimex Case
2024-02-23 Update README.md
    olimex case link
2024-03-08 Bezeichnung korrigiert
    Beschreibung J1 und J2 im Schaltplan war falsch.
    [opendtu V2.sch]
2024-04-18 Update Device Profil D1 ESP32.json
    Add Olimex PEO with NRF24L01 and Display
2024-07-30 ESP32 lange version
    ESP32 lang hinzugefügt

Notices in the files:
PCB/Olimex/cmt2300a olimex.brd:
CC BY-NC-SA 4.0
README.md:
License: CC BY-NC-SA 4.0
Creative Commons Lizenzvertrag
